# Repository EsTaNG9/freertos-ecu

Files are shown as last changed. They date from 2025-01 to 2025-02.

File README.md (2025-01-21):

<!-- Improved compatibility of back to top link: See: https://github.com/othneildrew/Best-README-Template/pull/73 -->

<!-- PROJECT LOGO -->
<br />
<div align="center">
  <a href="https:///github.com/EsTaNG9/freertos-ecu">
    
  </a>
   <h3></h3>
  <div align="center">
  <a href="https://github.com/https://github.com/EsTaNG9/freertos-ecu">
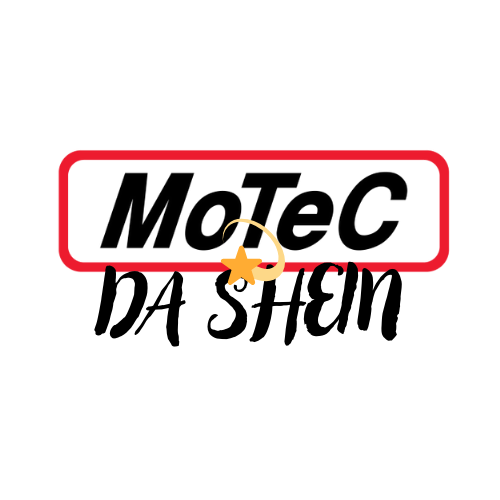
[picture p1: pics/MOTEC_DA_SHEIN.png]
    
  </a>
</div>

  <h3 align="center">FREERTOS ECU</h3>

  <p align="center">
    This is a poor attempt at developing a basic enegine managment system based on the ESP32 microprocessor.
    <br />
    <br />
    <a href="https://www.youtube.com/shorts/LGoChy05eWk">View Demo</a>
    ·
    <a href="https://github.com/EsTaNG9/freertos-ecu/issues/new?labels=bug&template=bug-report---.md">Report Bug</a>
    ·
    <a href="https://github.com/EsTaNG9/freertos-ecu/issues/new?labels=enhancement&template=feature-request---.md">Request Feature</a>
  </p>
</div>

<!-- ABOUT THE PROJECT -->
## About The Project

Our project consist on developing a simple engine management system for a 1 cylinder 4 or 2 stroke internal combustion engine.
The hear of this project was to develop a way to trigger the sparkplug at the correct time for each rotation of the engine. 

Limitações:
* The ESP32 only has 4 timers
* An PIC or ARM based microcontroller would be a better application, just because normally they have more timers available
* Falta de tempo para melhor desenvolver o projeto :smile:

Despite our efforts, the deadline came in quicly and unfortunately we didnt have time to finnish this project the our fullest capability.

<p align="right">(<a href="#readme-top">back to top</a>)</p>

### Materials

This is an example of how to list things you need to use the software and how to install them.
*	1x ESP32
*	1x Hall Sensor
*	4x Potentiometers (Emulate de CLT, IAT, MAP and TPS sensors)
*	1x ILI9341 320x240 SPI TFT LCD Display with Touch Sensor
*	3x LED´s + associated Resistors (Emulate Ignition Coil, Fuel Injector and Fuel Pump)
*	2x ESP32 Dev Kits (One as the controller the other has the Hall Sensor emulator)
*	Breadboard

<!-- ROADMAP -->
## Roadmap

- [x] Hall sensor triggering an interrupt
- [x] Trigger pattern 36-1 on the interrupt
- [x] DISPLAY
    - [x] Touch
    - [x] VE table
    - [x] IGN table
    - [x] Main page
- [x] Read + interpolate value from tables
- [x] ADC
    - [x] MAP
    - [x] IAT
    - [x] CLT
    - [x] TPS

See the [open issues](https://github.com/EsTaNG9/freertos-ecu/issues) for a full list of proposed features (and known issues).

<p align="right">(<a href="#readme-top">back to top</a>)</p>

<!-- CONTACT -->
## Contact

João Serrada - [@estang9](https://instagram.com/estang9) - 2192349@my.ipleiria.pt

Alexandre Bernardo - 2213099@my.ipleiria.pt

Project Link: [https://github.com/EsTaNG9/freertos-ecu](https://github.com/EsTaNG9/freertos-ecu)

Youtube Video Link: [https://youtube.com/shorts/LGoChy05eWk](https://youtube.com/shorts/LGoChy05eWk)

<p align="right">(<a href="#readme-top">back to top</a>)</p>

<!-- MARKDOWN LINKS & IMAGES -->
<!-- https://www.markdownguide.org/basic-syntax/#reference-style-links -->
[issues-shield]: https://img.shields.io/github/issues/othneildrew/Best-README-Template.svg?style=for-the-badge
[issues-url]: https://github.com/othneildrew/Best-README-Template/issues
[product-screenshot]: pics/MOTEC_DA_SHEIN.png

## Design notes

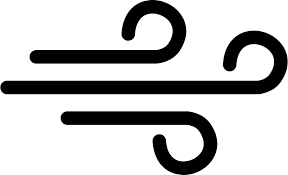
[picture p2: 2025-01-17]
pics/temp gases admi.png

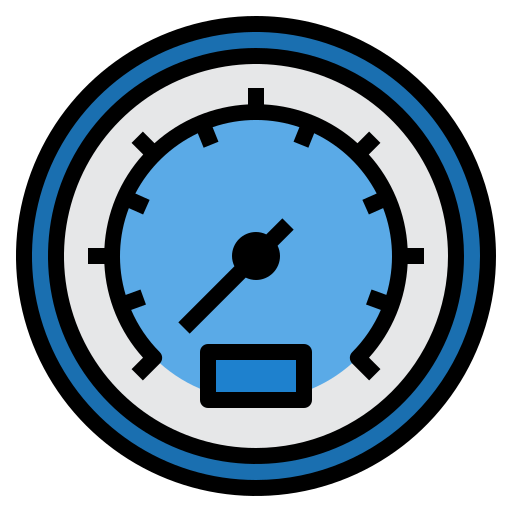
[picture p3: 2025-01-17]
pics/map.png

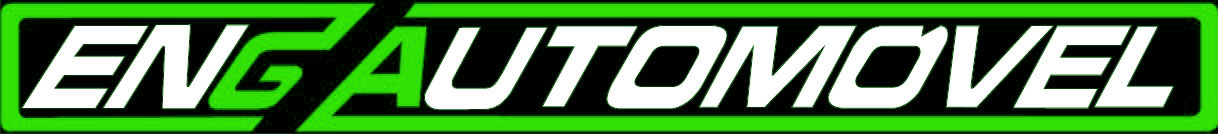
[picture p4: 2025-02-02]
pics/auto_jpg_verde1.jpg

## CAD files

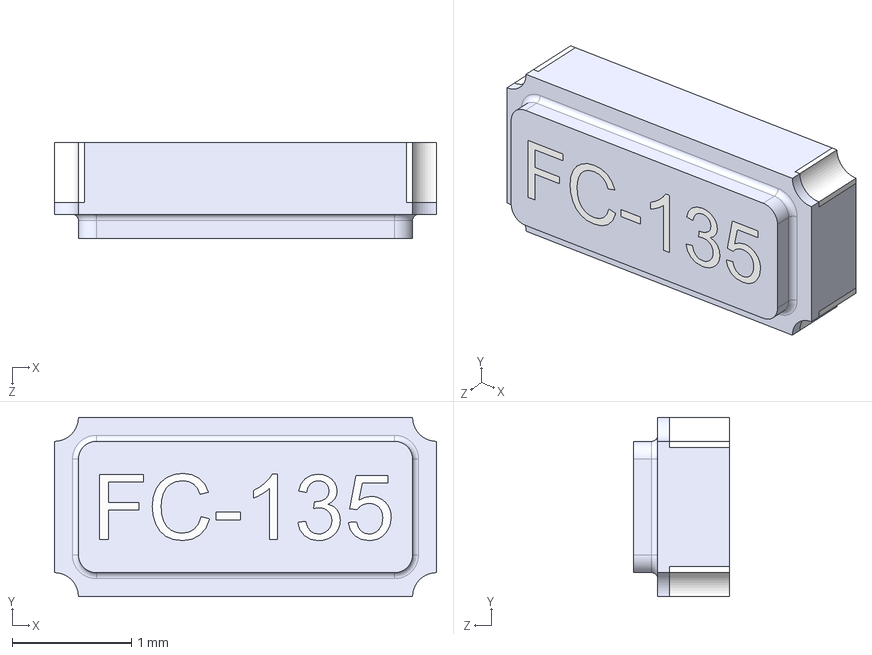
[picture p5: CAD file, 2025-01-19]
board/ecu_v0.1/ESP32-S2-Breakout/3d/FC-135.STEP
3.20 x 1.50 x 0.8 mm
Pin 2
Pin 1
Tekst Inlay

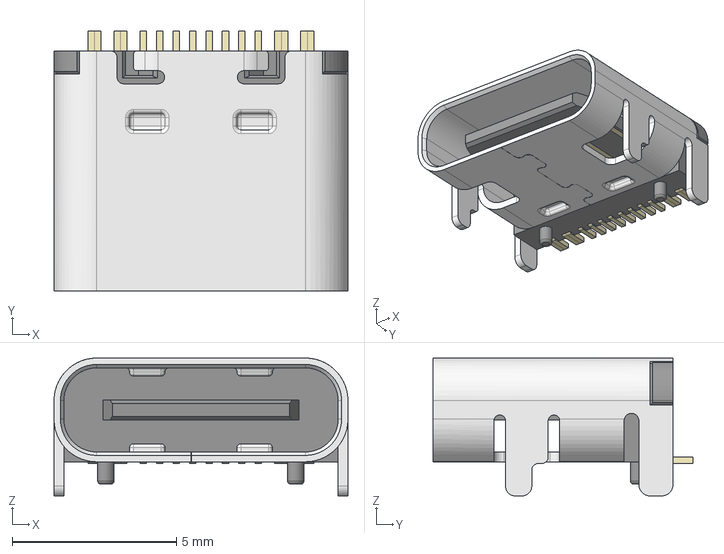
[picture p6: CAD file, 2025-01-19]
board/ecu_v0.1/ESP32-S2-Breakout/3d/HRO_TYPE-C-31-M-12.step
8.95 x 7.90 x 4.20 mm

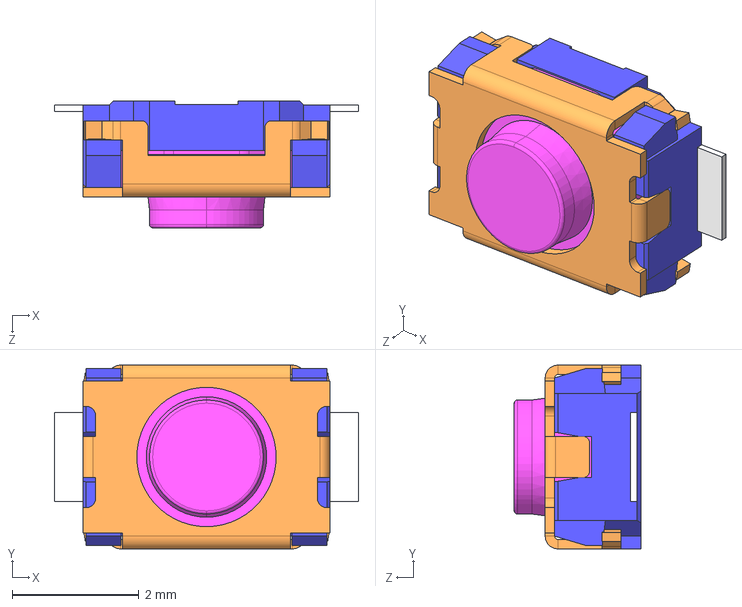
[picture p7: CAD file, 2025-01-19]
board/ecu_v0.1/ESP32-S2-Breakout/3d/SKRKAH.STEP
4.80 x 2.90 x 2.00 mm

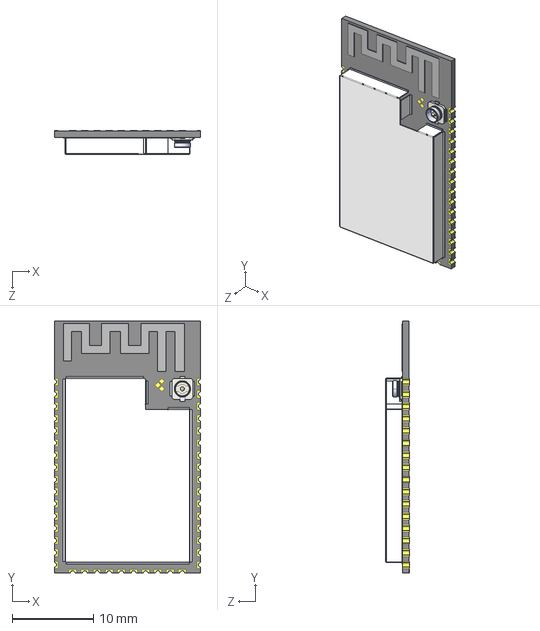
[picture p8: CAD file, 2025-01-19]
board/ecu_v0.1/ESP32-S2-Breakout/3d/ESP32-S2-WROVER.STEP
18.0 x 31.0 x 2.91 mm

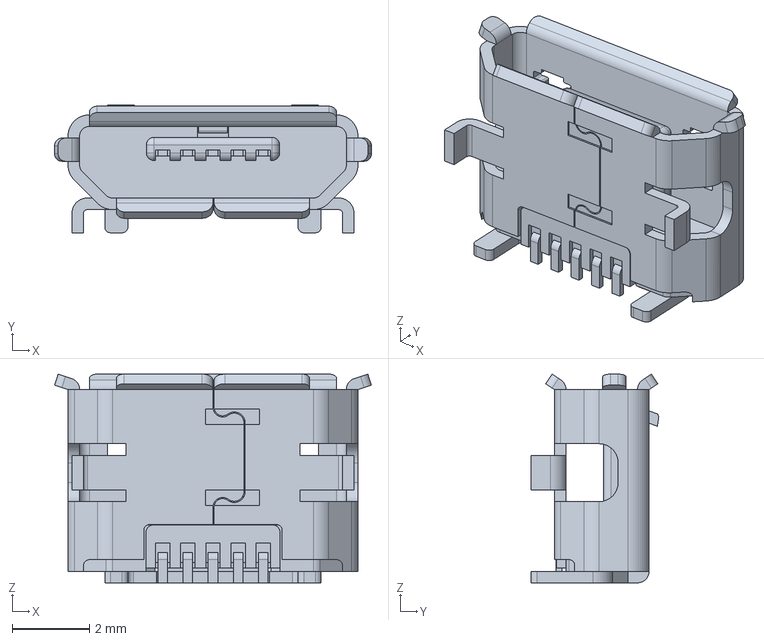
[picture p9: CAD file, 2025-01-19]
board/ecu_v0.1/ESP32-S2-Breakout/3d/1050170001.stp
8.20 x 3.30 x 5.40 mm

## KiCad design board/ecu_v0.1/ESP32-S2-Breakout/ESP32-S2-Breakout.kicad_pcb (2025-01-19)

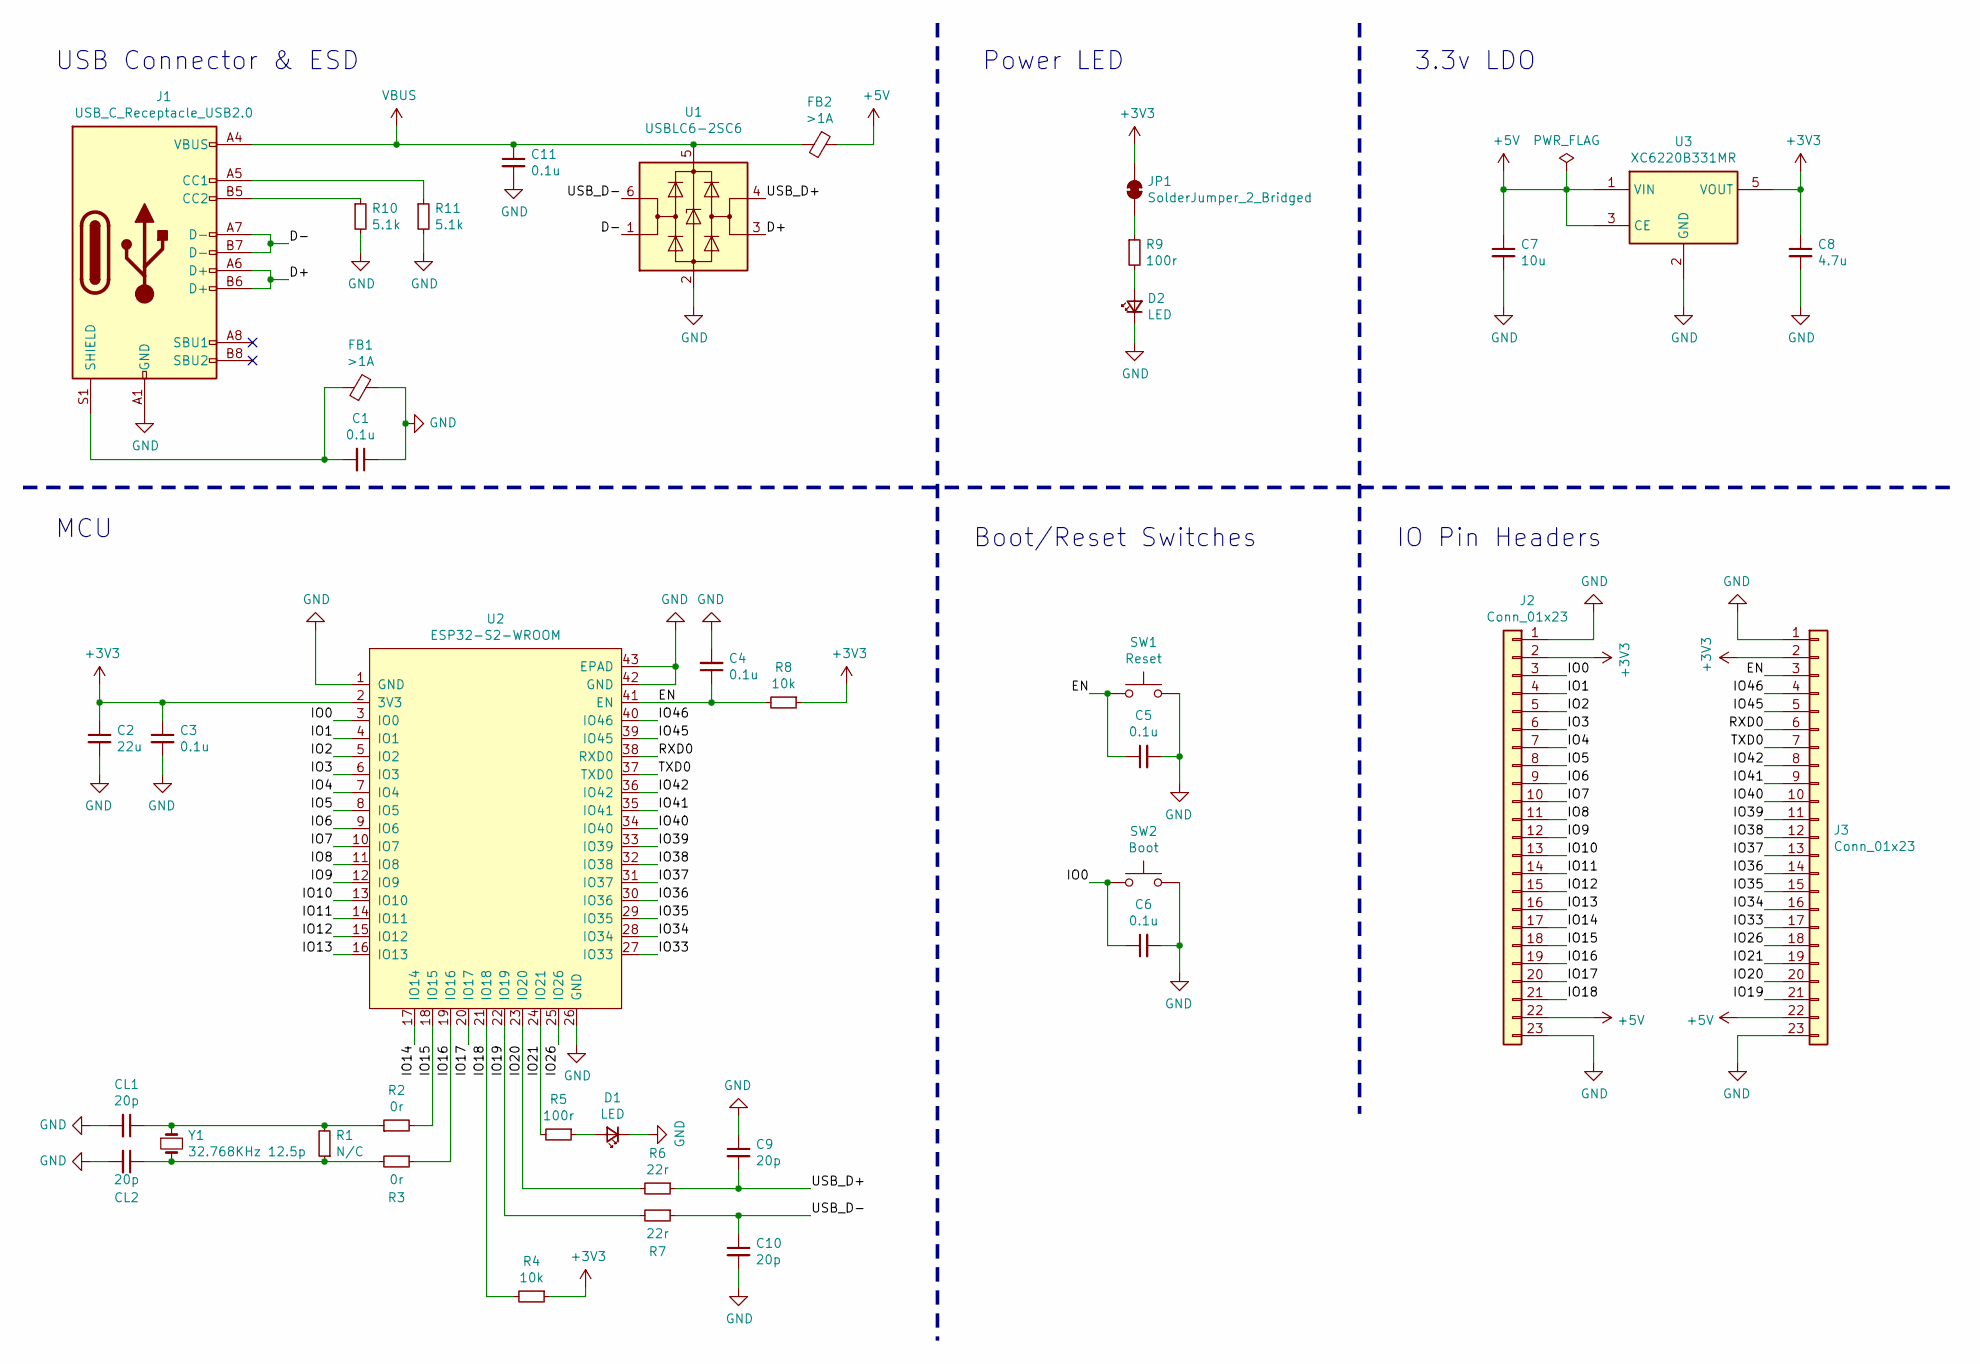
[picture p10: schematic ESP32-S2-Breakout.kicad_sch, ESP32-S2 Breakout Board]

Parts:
C1, C3, C4, C5, C6, C11: 0.1u; C_0603_1608Metric; LCSC C14663
C2: 22u; C_0603_1608Metric; LCSC C84419
C7: 10u; C_0603_1608Metric; LCSC C90058
C8: 4.7u; C_0603_1608Metric; LCSC C69335
C9, C10: 20p; C_0603_1608Metric; LCSC C1648
CL1, CL2: 20p; C_0603_1608Metric; LCSC C1648
D1: LED; LED_0603_1608Metric; LCSC C205443
D2: LED; LED_0603_1608Metric; LCSC C205445
FB1, FB2: >1A; L_0603_1608Metric; LCSC C24821
J1: USB_C_Receptacle_USB2.0; USB_C_Receptacle_HRO_TYPE-C-31-M-12; LCSC C165948
J2, J3: Conn_01x23; PinHeader_1x23_P2.54mm_Vertical
JP1: SolderJumper_2_Bridged; SolderJumper-2_P1.3mm_Bridged_RoundedPad1.0x1.5mm
R1: N/C; R_0603_1608Metric
R2, R3: 0r; R_0603_1608Metric; LCSC C21189
R4, R8: 10k; R_0603_1608Metric; LCSC C99198
R5, R9: 100r; R_0603_1608Metric; LCSC C22775
R6, R7: 22r; R_0603_1608Metric; LCSC C23345
R10, R11: 5.1k; R_0603_1608Metric; LCSC C163928
SW1: Reset; Alps_SKRK; LCSC C115357
SW2: Boot; Alps_SKRK; LCSC C115357
U1: USBLC6-2SC6; SOT-23-6; LCSC C7519
U2: ESP32-S2-WROOM; LCSC C701327
U3: XC6220B331MR; SOT-23-5; LCSC C86534
Y1: 32.768KHz 12.5p; Crystal_SMD_3215-2Pin_3.2x1.5mm; LCSC C271654

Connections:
+3V3: C2.1, C3.1, C8.1, J2.2, J3.2, JP1.1 (A), R4.1, R8.1, U2.2 (3V3), U3.5 (VOUT)
+5V: C7.1, FB2.1, J2.22, J3.22, U3.1 (VIN), U3.3 (CE)
/D+: J1.A6 (D+), J1.B6 (D+), U1.3 (I/O2)
/D-: J1.A7 (D-), J1.B7 (D-), U1.1 (I/O1)
/EN: C4.1, C5.1, J3.3, R8.2, SW1.2, U2.41 (EN)
/IO0: C6.1, J2.3, SW2.2, U2.3 (IO0)
/IO1: J2.4, U2.4 (IO1)
/IO2: J2.5, U2.5 (IO2)
/IO3: J2.6, U2.6 (IO3)
/IO4: J2.7, U2.7 (IO4)
/IO5: J2.8, U2.8 (IO5)
/IO6: J2.9, U2.9 (IO6)
/IO7: J2.10, U2.10 (IO7)
/IO8: J2.11, U2.11 (IO8)
/IO9: J2.12, U2.12 (IO9)
/IO10: J2.13, U2.13 (IO10)
/IO11: J2.14, U2.14 (IO11)
/IO12: J2.15, U2.15 (IO12)
/IO13: J2.16, U2.16 (IO13)
/IO14: J2.17, U2.17 (IO14)
/IO15: J2.18, R2.2, U2.18 (IO15)
/IO16: J2.19, R3.1, U2.19 (IO16)
/IO17: J2.20, U2.20 (IO17)
/IO18: J2.21, R4.2, U2.21 (IO18)
/IO19: J3.21, R7.2, U2.22 (IO19)
/IO20: J3.20, R6.2, U2.23 (IO20)
/IO21: J3.19, R5.2, U2.24 (IO21)
/IO26: J3.18, U2.25 (IO26)
/IO33: J3.17, U2.27 (IO33)
/IO34: J3.16, U2.28 (IO34)
/IO35: J3.15, U2.29 (IO35)
/IO36: J3.14, U2.30 (IO36)
/IO37: J3.13, U2.31 (IO37)
/IO38: J3.12, U2.32 (IO38)
/IO39: J3.11, U2.33 (IO39)
/IO40: J3.10, U2.34 (IO40)
/IO41: J3.9, U2.35 (IO41)
/IO42: J3.8, U2.36 (IO42)
/IO45: J3.5, U2.39 (IO45)
/IO46: J3.4, U2.40 (IO46)
/RXD0: J3.6, U2.38 (RXD0)
/TXD0: J3.7, U2.37 (TXD0)
/USB_D+: C9.2, R6.1, U1.4 (I/O2)
/USB_D-: C10.1, R7.1, U1.6 (I/O1)
GND: C1.1, C2.2, C3.2, C4.2, C5.2, C6.2, C7.2, C8.2, C9.1, C10.2, C11.2, CL1.2, CL2.2, D1.1 (K), D2.1 (K), FB1.2, J1.A1 (GND), J1.A12 (GND), J1.B1 (GND), J1.B12 (GND), J2.1, J2.23, J3.1, J3.23, R10.2, R11.2, SW1.1, SW2.1, U1.2 (GND), U2.1 (GND), U2.26 (GND), U2.42 (GND), U2.43 (EPAD), U3.2 (GND)
unnamed: C1.2, FB1.1, J1.S1 (SHIELD)
unnamed: CL1.1, R1.2, R2.1, Y1.1
unnamed: CL2.1, R1.1, R3.2, Y1.2
unnamed: D1.2 (A), R5.1
unnamed: D2.2 (A), R9.2
unnamed: J1.A5 (CC1), R11.1
unnamed: J1.B5 (CC2), R10.1
unnamed: JP1.2 (B), R9.1
VBUS: C11.1, FB2.2, J1.A4 (VBUS), J1.A9 (VBUS), J1.B4 (VBUS), J1.B9 (VBUS), U1.5 (VBUS)

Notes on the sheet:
USB Connector & ESD
IO Pin Headers
3.3v LDO
MCU
Boot/Reset Switches
Power LED

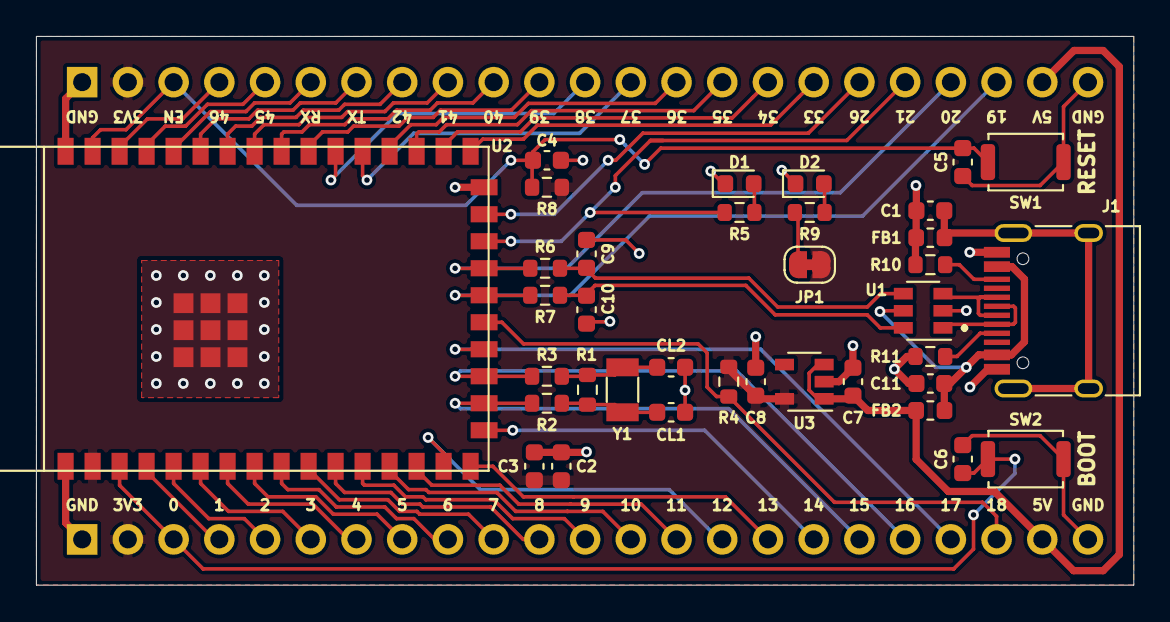
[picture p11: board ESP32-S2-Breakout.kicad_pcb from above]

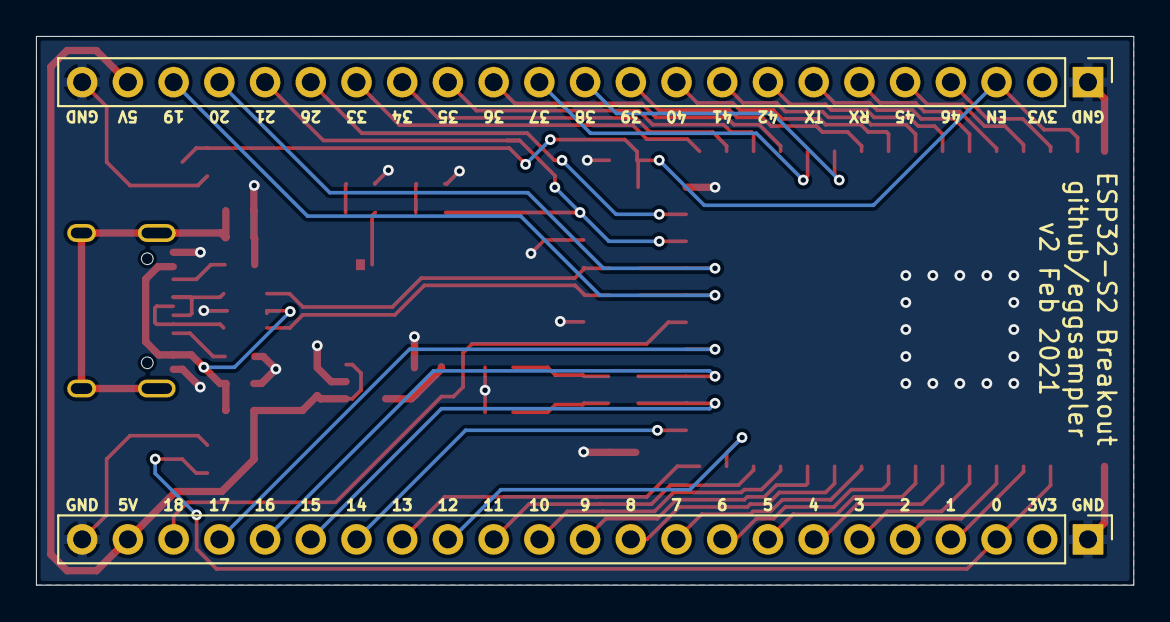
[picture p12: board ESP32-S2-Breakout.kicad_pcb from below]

Board: 2 copper layers, 61.0 x 30.5 mm, 38 parts (2 on the bottom side), 54 nets.

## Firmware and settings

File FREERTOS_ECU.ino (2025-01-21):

/*
 Alexandre Bernardo Nº2213099
 João Serrada Nº2192349
 IPLEIRIA - Instituto Politécnico de Leiria
 ESTG - Escola Superior de Tecnologia e Gestão
 EAU - Licenciatura em Engenharia Automóvel
 SEEV - Sistemas Elétricos e Eletrónicos de Veículos

 TP1: Pretende-se desenvolver uma controlador básico para um motor de combustão interna monocilindrico a injeção e ignição eletronicas

 LINK: https://youtube.com/shorts/LGoChy05eWk?si=FkxpbRwJG1KGSUmk
 */

#include <math.h>
#include "Arduino.h"
#include <stdio.h>
#include "freertos/FreeRTOS.h"
#include "freertos/task.h"
#include "esp_system.h"
#include "nvs_flash.h"
#include "esp_task_wdt.h"
#include "driver/ledc.h"
#include "esp_err.h"
#include <SPI.h>
#include <Adafruit_GFX.h>
#include <Adafruit_ILI9341.h>
#include <XPT2046_Touchscreen.h>

// Imagens em bitmap
#include "engauto.h" //logo automovel
#include "logo_map.h" //logo map
#include "logo_temp_motor.h" //logo temp_motor
#include "logo_avanco.h"
#include "logo_temp_gases_adm.h" //logo logo_humidade
#include "logo_tps.h" //logo logo_tps
#include "logo_rpm.h" //logo logo_rpm

//Mapas de igniçao e injecao
#include "tables.h"

//Caso não haja sinal em 1000ms, ent o motor foi abaixo
#define TEMPO_MAXIMO_MOTOR_MORRER 1000 //mS

//Config do ADC
#define ADC_RESOLUTION 6
#define VREF_PLUS  5
#define VREF_MINUS  0.0

//Calibração dos sensores
#define MAP_5V  100 //kpa
#define MAP_0V 10 //kpa

#define TPS_5V  100 //%
#define TPS_0V 0 //%

#define CLT_5V  120 //ºC
#define CLT_0V -10 //ºC

#define IAT_5V  80 //ºC
#define IAT_0V 5 //ºC

//Sistema de debug
#define DEBUG "OFF"
#define DEBUG_LEVEL 2

// Definir os terminais do LCD
#define TFT_CS   05
#define TFT_DC   26
#define TFT_MOSI 23
#define TFT_MISO 19
#define TFT_SCLK 18
#define TFT_RST -1 // ligar ao 3V3

// Pinos do controlador Touch
#define XPT2046_IRQ 36   // T_IRQ
#define XPT2046_MOSI 27  // T_DIN
#define XPT2046_MISO 39  // T_OUT
#define XPT2046_CLK 25   // T_CLK
#define XPT2046_CS 14    // T_CS

//Dimensão do display
#define SCREEN_WIDTH 320
#define SCREEN_HEIGHT 240

//Configuração da injeção
#define INJ1_FREQ 1000 //Se o injector deadtime for 1ms@12V
#define INJ1_TIMER LEDC_TIMER_3//Selecionar o timer a ser usado
#define INJ1_RESO LEDC_TIMER_13_BIT//Resolução do timer utilizado
#define INJ1_MODE LEDC_LOW_SPEED_MODE
#define INJ1_CHANNEL LEDC_CHANNEL_0
#define INJ1_MAX_DUTY ((1 << 13) - 1)// Max duty (8191 for 13 bits)

// Criar um objeto tft com indicação dos terminais CS e DC
Adafruit_ILI9341 tft = Adafruit_ILI9341(TFT_CS, TFT_DC, TFT_MOSI, TFT_SCLK,
TFT_RST, TFT_MISO);

SPIClass touchscreenSPI = SPIClass(VSPI);
XPT2046_Touchscreen touchscreen(XPT2046_CS, XPT2046_IRQ);

/* The service routine for the interrupt.  This is the interrupt that the task
 will be synchronized with. */
void IRAM_ATTR onPulse(void);
void coilDischargeTimer_callback(void *arg);

/* The tasks to be created. */
void vDisplay(void *pvParameters);
void vBrain(void *pvParameters);
void vInterpolacao(void *pvParameters);

//Declarar funcoes
int getCrankAngle(long, long, int);
int getLowRPM(long, long, int);
void prntIGN(void);
float interpolation(int, int, int);
float getADC(int);
//void setup_timers(void);

// Estruturas
typedef struct {
	bool proxima;
	bool antes;
	int pagina_atual;
} pagina_t;

typedef struct {
	bool sincronizacao;
	bool descargaBobine;
	bool bombaCombustivel;
	int RPM;
	uint16_t atualRPS;
	uint16_t ContadorDentes;
	uint16_t contadorrevolucoes;
	uint16_t avancoIGN;
	uint16_t dutyVE;
	long tempoUltimoDente;
	long tempoPenultimoDente;
	long tempoFiltro;
	long tempoPrimeiroDenteMenosUm;
	long tempoPrimeiroDente;
	long tempoPorGrau;
	long falhaAtual;
	long timerIGN;
	float MAP;
	float TPS;
	float CLT;
	float IAT;
} ecu_info_t;

//Handles
QueueHandle_t xECU;
QueueHandle_t xPagina;

/* Protoripoa de semaforos para sincronizacao de interrupcoees*/
SemaphoreHandle_t xPaginaMutex;
SemaphoreHandle_t xECUMutex;
SemaphoreHandle_t xInterpolacao; // Binary semaphore

// Timers
esp_timer_handle_t coilTimer; //Definir a handle globalmente para a poder chamar na interrupcao

// pin to generate interrupts
const uint8_t interruptPin = 4;
//const uint8_t bombaCombustivelPin = 28;
const uint8_t MAPSensorPin = 35;
const uint8_t bobine1Pin = 32;
const uint8_t injetor1Pin = 33;

//Configurar roda fonica
uint16_t numRealDentes = 35;
uint16_t anguloPorDente = 360 / 36;
uint16_t desvioPrimeiroDenteTDC = 180; //Desvio real do TDC 1ºcil do primeiro dente da roda

void setup(void) {
	// Set loopTask max priority before deletion
	vTaskPrioritySet(NULL, configMAX_PRIORITIES - 1);

	// Init USART and set Baud-rate to 115200
	Serial.begin(115200);

	//setup adc
	analogReadResolution(ADC_RESOLUTION);

	//Interrupção Hall Sensor
	pinMode(interruptPin, INPUT);
	pinMode(bobine1Pin, OUTPUT);
	pinMode(injetor1Pin, OUTPUT);
	pinMode(MAPSensorPin, INPUT_PULLUP);
	pinMode(XPT2046_CS, OUTPUT);
	//attachInterrupt(digitalPinToInterrupt(interruptPin), onPulse, RISING);

	//Tive q definir primeiro o pwm, pq dps da erro, presumidamente, o esp tentava acessar dois timers iguais
	ledc_timer_config_t inj1_timer = { .speed_mode = INJ1_MODE, .duty_resolution = INJ1_RESO, .timer_num = INJ1_TIMER, .freq_hz = INJ1_FREQ, .clk_cfg = LEDC_AUTO_CLK };
	ESP_ERROR_CHECK(ledc_timer_config(&inj1_timer));

	// Configure the LEDC channel
	ledc_channel_config_t inj1_channel = { .gpio_num = injetor1Pin, .speed_mode = INJ1_MODE, .channel = INJ1_CHANNEL, .intr_type = LEDC_INTR_DISABLE, .timer_sel = INJ1_TIMER, .duty = 0, .hpoint = 0 };
	ESP_ERROR_CHECK(ledc_channel_config(&inj1_channel));

	//timers
	esp_timer_create_args_t coilTimer_args = { .callback = &coilDischargeTimer_callback, .arg = NULL, .name = "coilTimer" };
	ESP_ERROR_CHECK(esp_timer_create(&coilTimer_args, &coilTimer));

	//queues
	xECU = xQueueCreate(1, sizeof(ecu_info_t));
	xPagina = xQueueCreate(1, sizeof(pagina_t));

	//Semafro Mutex
	xPaginaMutex = xSemaphoreCreateMutex();
	xECUMutex = xSemaphoreCreateMutex();

	//semaforo sincronizador
	xInterpolacao = xSemaphoreCreateBinary();

	//Assegurar valores iniciais nas queues
	pagina_t initPagina = { false, false, 0 };
	xQueueSend(xPagina, &initPagina, portMAX_DELAY);

	ecu_info_t initECU = { false, LOW, LOW, 0, 0, 35, 0, 10, 1, 0, 0, 0, 0, 0, 0, 100, 1000, 0, 90, 90 };
	xQueueSend(xECU, &initECU, portMAX_DELAY);

	// Criar tarefas
	xTaskCreatePinnedToCore(vDisplay, "vDisplay", 4096, NULL, 2, NULL, 1);
	xTaskCreatePinnedToCore(vBrain, "vBrain", 4096, NULL, 2, NULL, 1);
	xTaskCreatePinnedToCore(vInterpolacao, "vInterpolacao", 4096, NULL, 1, NULL, 1);
	//xTaskCreatePinnedToCore(vTouchDetection, "detectar touch", 8192, NULL, 3, NULL, 1);

	//iniciar interrupcoes apenas dps de correr o setup
	attachInterrupt(digitalPinToInterrupt(interruptPin), onPulse, RISING);

	if (DEBUG == "ON" && DEBUG_LEVEL <= 3) {
		Serial.println("Setup acabou de correr");
	}

}

void vBrain(void *pvParameters) {
	pagina_t updateValores;
	ecu_info_t getECU;
	portBASE_TYPE xStatus;
	unsigned long temp_tempoUltimoDente = 0, tempoUltimoDente = 1;
	int temp_atualRPM = 0, atualRPM = 0;
	float temp_voltage = 0;

	while (true) {
		//Obter o "tempo" de quando o ciclo while doi reiniciado
		long tempoAtual_Brain = micros();

		//Obter valores da queue
		if (xQueuePeek(xECU, &getECU, (TickType_t) 250) == pdPASS) {
		}

		//Obter quanto tempo passou desde a detectação do último dente
		unsigned long tempoParaUltimoDente = (tempoAtual_Brain - getECU.tempoUltimoDente);

		//Serial.println("Brain: RUNNING");

		//Verificvamos de o motor sequer está a rodar
		if (tempoParaUltimoDente < (TEMPO_MAXIMO_MOTOR_MORRER * 1000)) {
			int ultimaRPM = atualRPM;
			//atualRPM = getECU.RPM;

			atualRPM = getLowRPM(getECU.tempoUltimoDente, getECU.tempoPenultimoDente, getECU.RPM);

			/*Serial.print("RPM: ");
			 Serial.println(atualRPM);*/

			if (getECU.bombaCombustivel == false) {
				//digitalWrite(bombaCombustivel, HIGH);
				getECU.bombaCombustivel = true;
			} //Check if the fuel pump is on and turn it on if it isn't.

		} else {
			atualRPM = 0;
			getECU.contadorrevolucoes = 0;
			getECU.bombaCombustivel = false;
			//bombaCombustivel = false;
			getECU.sincronizacao = false;
			getECU.atualRPS = 0;
			//Serial.println("Brain: ENGINE DEAD :(");
		}

		if (getECU.sincronizacao && (atualRPM > 0)) {

			// future development
		}

		//Updatar o valor MAP
		temp_voltage = getADC(MAPSensorPin);
		float temp_MAP = temp_voltage * (MAP_0V - MAP_5V) / (VREF_MINUS - VREF_PLUS);
		getECU.MAP = temp_MAP;

		//Updatar o valor TPS
		temp_voltage = getADC(MAPSensorPin);
		float temp_TPS = temp_voltage * (TPS_0V - TPS_5V) / (VREF_MINUS - VREF_PLUS);
		getECU.TPS = temp_TPS;

		//Updatar o valor IAT
		temp_voltage = getADC(MAPSensorPin);
		float temp_IAT = temp_voltage * (IAT_0V - IAT_5V) / (VREF_MINUS - VREF_PLUS);
		getECU.IAT = temp_IAT;

		//Updatar o valor CLT
		temp_voltage = getADC(MAPSensorPin);
		float temp_CLT = temp_voltage * (CLT_0V - CLT_5V) / (VREF_MINUS - VREF_PLUS);
		getECU.CLT = temp_CLT;

		getECU.RPM = atualRPM;

		//Atualizar a Queue principal
		if (xQueueOverwrite(xECU, &getECU) == pdPASS) {
		}

		//Código de detecção touch
		if (touchscreen.tirqTouched() && touchscreen.touched() && xSemaphoreTake(xPaginaMutex, portMAX_DELAY) == pdTRUE && xQueuePeek(xPagina, &updateValores, 0) == pdPASS) {
			int x, y, z;
			// Get Touchscreen points
			TS_Point p = touchscreen.getPoint();
			// Calibrate Touchscreen points with map function to the correct width and height
			x = map(p.x, 200, 3700, 1, SCREEN_WIDTH); //COORDENADA X
			y = map(p.y, 240, 3800, 1, SCREEN_HEIGHT); //COORDENADA Y
			z = p.z; //PRESSAO

			if (x < 160) {
				//Serial.print("NEXTTTT");
				updateValores.proxima = true;
				updateValores.antes = false; //redundancia

			} else {
				//Serial.print("PREVIOUS");
				updateValores.antes = true;
				updateValores.proxima = false; //redundancia
			}

			xQueueOverwrite(xPagina, &updateValores);
			xSemaphoreGive(xPaginaMutex);

		}

		if ( DEBUG == "ON" && DEBUG_LEVEL <= 2) {
			Serial.print("Correu a task: ");
			Serial.println(pcTaskGetTaskName(NULL));
		}
		vTaskDelay(25 / portTICK_PERIOD_MS);
	}
}

/* Nota: n estou a conseguir implementar as queeue peeks sem crashar cpu*/
int getCrankAngle(long tempoUltimoDente, long tempoPorGrau, int contadorDentes) {
	unsigned long temp_tempoUltimoDente;
	//unsigned long tempoUltimoDente = 1; // n pode ser volatile pq quero mandar valores para a queeue
	//int temp_contadorDentes;

// Prioridade máxima

	//xQueuePeek(xContadorDentes, &temp_contadorDentes, (TickType_t) 10); //portMAX_DELAY
	//xQueuePeek(xtempoUltimoDente, &temp_tempoUltimoDente, (TickType_t) 10);
	//Prioridade normal

	//int anguloCambota = ((temp_contadorDentes - 1) * anguloPorDente) + desvioPrimeiroDenteTDC;
	int anguloCambota = ((contadorDentes - 1) * anguloPorDente) + desvioPrimeiroDenteTDC;

	//Estimar o num de graus desde o ultimo dente
	//long tempoDecorridoDesdeUltimoDente = micros() - temp_tempoUltimoDente;
	long tempoDecorridoDesdeUltimoDente = micros() - tempoUltimoDente;
	//Serial.println("erro 0");
	//tempoPorGrau = (temp_tempoUltimoDente / anguloPorDente); //Se n funcionar faço apartir da rpm
	tempoPorGrau = (tempoUltimoDente / anguloPorDente); //Se n funcionar faço apartir da rpm

	anguloCambota = anguloCambota + ldiv(tempoDecorridoDesdeUltimoDente, tempoPorGrau).quot;
	//Serial.println(anguloCambota);

	if (anguloCambota > 360) {
		anguloCambota = anguloCambota - 360;
	}

	return anguloCambota;
}

int getLowRPM(long temp_tempoUltimoDente, long temp_tempoPenultimoDente, int temp_RPMatual) {

	//unsigned long temp_tempoUltimoDente = 1, temp_tempoPenultimoDente = 0;

	int tempoEntreDentes = (temp_tempoUltimoDente - temp_tempoPenultimoDente);
	if (tempoEntreDentes == 0) {
		return temp_RPMatual;
	} else {

		int rpm_temporary = (((60000000 / (tempoEntreDentes * 36)) + 1) * 2); //+1 pq falha, n sei pk x2??
		return rpm_temporary;
	}
	//Serial.println("	gay");
}

void coilDischargeTimer_callback(void *arg) {

	digitalWrite(bobine1Pin, HIGH); //Descarregar bobine

	//prntIGN();
}

// Interrupção gerada na transição do sinal do sensor de Hall
void IRAM_ATTR onPulse(void) {
	ecu_info_t updateECU;
	unsigned long falhaAtual = 0, falhaObjetivo = 0, tempoFiltro = 0, tempoAtual = 0; // n pode ser volatile pq quero mandar valores para a queeue
	BaseType_t xHigherPriorityTaskWoken;

	if (xQueueReceiveFromISR(xECU, &updateECU, &xHigherPriorityTaskWoken) == pdPASS) {

		xQueueSendFromISR(xECU, &updateECU, &xHigherPriorityTaskWoken);
	}

	tempoAtual = micros();
	falhaAtual = tempoAtual - updateECU.tempoUltimoDente;

	if (falhaAtual < updateECU.tempoFiltro) {
		//Serial.println("Debounce");
	} else {

		falhaObjetivo = 1.5 * (updateECU.tempoUltimoDente - updateECU.tempoPenultimoDente);

		if (falhaAtual > falhaObjetivo || updateECU.ContadorDentes > numRealDentes) {

			updateECU.ContadorDentes = 1;
			updateECU.tempoPrimeiroDenteMenosUm = updateECU.tempoPrimeiroDente;
			updateECU.tempoPrimeiroDente = tempoAtual;
			updateECU.sincronizacao = true;
			updateECU.contadorrevolucoes++;
			updateECU.descargaBobine = LOW;

			//setup injecao  -- DA ERRO QND TENTO INICIALIZAR O DUTY CYCLE
			ESP_ERROR_CHECK(ledc_set_duty(INJ1_MODE, INJ1_CHANNEL, updateECU.dutyVE));
			ESP_ERROR_CHECK(ledc_update_duty(INJ1_MODE, INJ1_CHANNEL));

		} else {
			updateECU.tempoFiltro = falhaAtual * 0.25; // 25% de filtro
			updateECU.ContadorDentes++;
		}

		if (updateECU.ContadorDentes == 3) {

			if (esp_timer_is_active(coilTimer) == 0) { // supostamente nunca vai retornar 1 pq o timer demora menos tempo que uma rotacao completa da cambota
				ESP_ERROR_CHECK(esp_timer_start_once(coilTimer, updateECU.timerIGN));
			}
			//Serial.println("TIMER HAS BEEN TRIGGERED!!!!!");
		}

		updateECU.tempoPenultimoDente = updateECU.tempoUltimoDente;
		updateECU.tempoUltimoDente = tempoAtual;
		updateECU.falhaAtual = falhaAtual;

		digitalWrite(bobine1Pin, LOW); //Carregar a bobine

		xQueueOverwriteFromISR(xECU, &updateECU, &xHigherPriorityTaskWoken);

		//Semafro binário para sincronizar a interrupção com a Task vInterpolacao
		xSemaphoreGiveFromISR(xInterpolacao, &xHigherPriorityTaskWoken);
	}
}

void vInterpolacao(void *pvParameters) {
	ecu_info_t updateECU;
	while (1) {
		if (xSemaphoreTake(xInterpolacao, portMAX_DELAY)) {

			if (xQueuePeek(xECU, &updateECU, portMAX_DELAY) == pdPASS) {

				//INTERPOLACAO

				int temp_MAP = (int) updateECU.MAP;
				int temp_RPM = updateECU.RPM;

				//VE
				float interpolacao_result = (interpolation(temp_MAP, temp_RPM, 1) / 0.012); // y = 0,012x (X0; Y0),(X8191;Y100)
				int duty = (int) interpolacao_result;

				//IGN
				int ign_result = interpolation(temp_MAP, temp_RPM, 0);

				updateECU.avancoIGN = ign_result;
				updateECU.dutyVE = duty;

				//GESTAO DA IGNIÇÃO

				float tempoPorGrau = (updateECU.falhaAtual / anguloPorDente);
				float anguloDisparo = (desvioPrimeiroDenteTDC - updateECU.avancoIGN) - getCrankAngle(updateECU.tempoUltimoDente, (int) tempoPorGrau, updateECU.ContadorDentes);
				long timerIGN = long(anguloDisparo * tempoPorGrau);

				updateECU.timerIGN = timerIGN;
				//Serial.println(tempoPorGrau);
				//Serial.println(anguloDisparo);
				//Serial.println(tempoPorGrau);
				//Serial.println(updateECU.falhaAtual);

				xQueueOverwrite(xECU, &updateECU);

				if ( DEBUG == "ON" && DEBUG_LEVEL <= 2) {
					Serial.println(duty);
					Serial.println(ign_result);
				}

			}
		}
	}
}
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
void loop() {
	vTaskDelete(NULL);
}

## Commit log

2024-12-03 a12 compiled but crashing
    [FREERTOS_ECU.ino]
2024-12-05 a14 sinal de vida
    interrupcao a funfar e getRPM tb a funfar
2024-12-09 a15 not crashing
    progresso omg
    [FREERTOS_ECU.ino]
2024-12-12 a16 timer implementado
2024-12-14 a17 timer e interrupção a funfar
2025-01-02 a19
    atleast it doesnt fcking crash
    [FREERTOS_ECU.ino]
2025-01-09 a20
    tabela de avanço
    [ign_table.csv, partitions.csv]
2025-01-13 a21
    injecgtor pwm setted up
2025-01-14 a22
    starting on getting adc values
2025-01-17 a23
    adc adicionado
2025-01-19 a25
    going to main, small things crashing processor so theyre are commented
    [FREERTOS_ECU.ino]
2025-01-19 v0.1
    housekeeping de código
    alinhamento de icon no display
2025-01-19 v0.2
    remoção das variáveis globais
    [1050170001.stp, ESP32-S2-Breakout.kicad_pcb, ESP32-S2-Breakout.kicad_sch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]
2025-01-19 v0.3
    pequena modificação no logo da temp do motor
2025-01-20 v0.4
    pwm injetor a trabalhar
2025-01-20 V0.5
    timer de ignicao implementado, mas ainda falta definir o disparo correto
